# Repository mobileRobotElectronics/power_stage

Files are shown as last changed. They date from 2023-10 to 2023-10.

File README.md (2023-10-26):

# power-stage
Power stage designed for a mobile robot during a practical course at Karlsruhe Institute of Technology

This repository includes both the schematic and the PCD design of the power stage. Designed and edited using [KicCad7.0](https://www.kicad.org/).

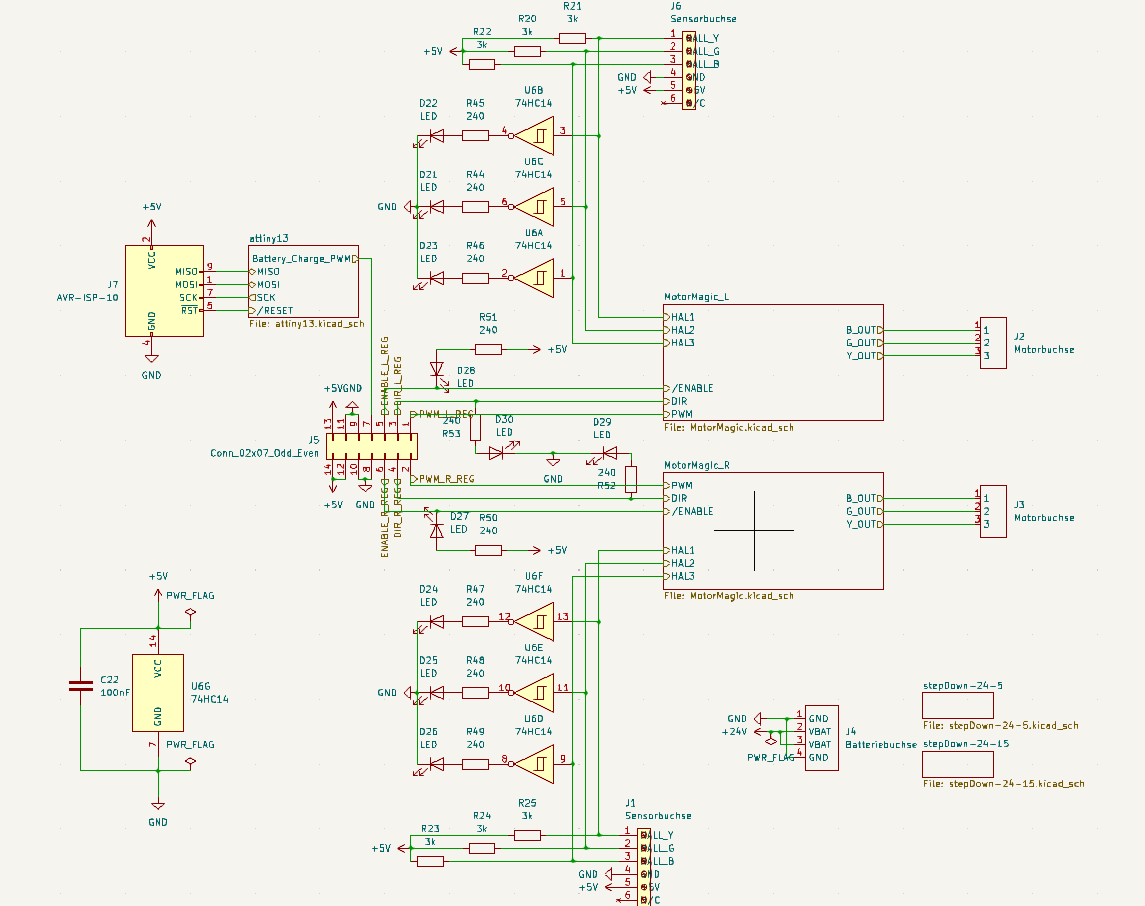
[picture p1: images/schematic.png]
schematic

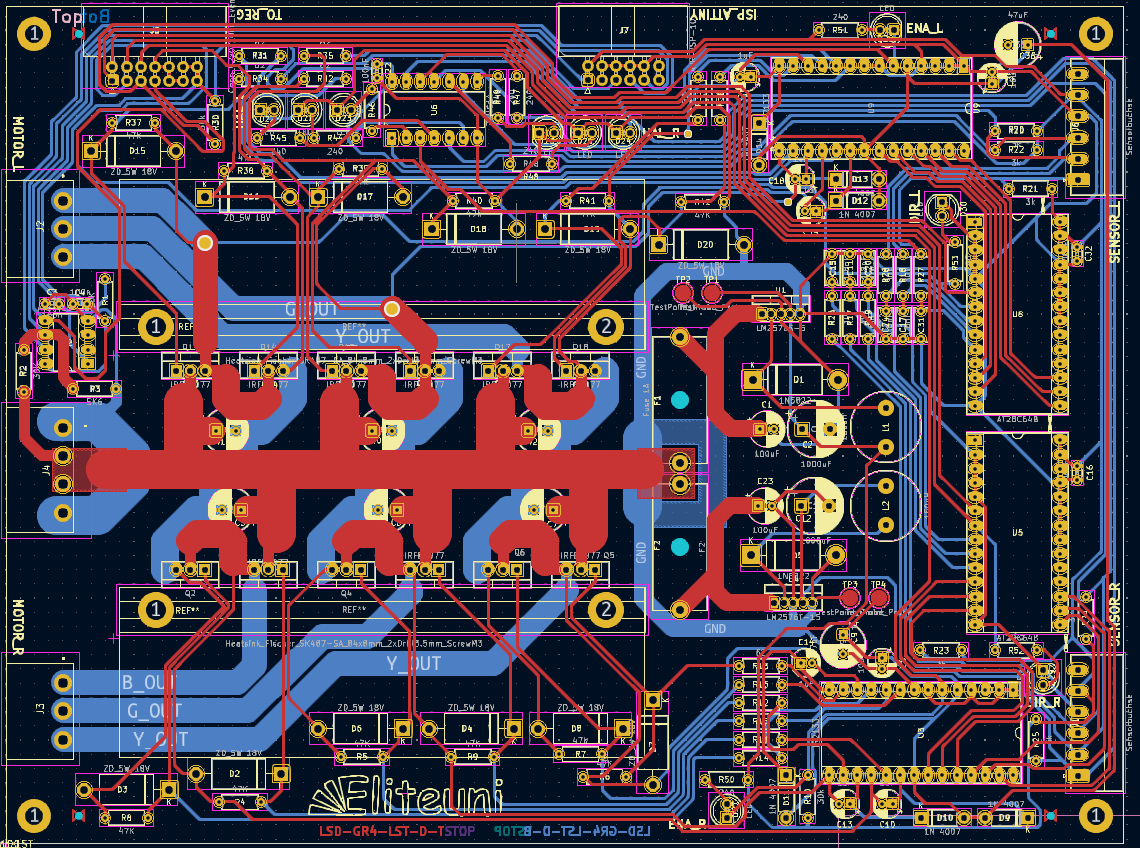
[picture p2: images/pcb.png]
pcd

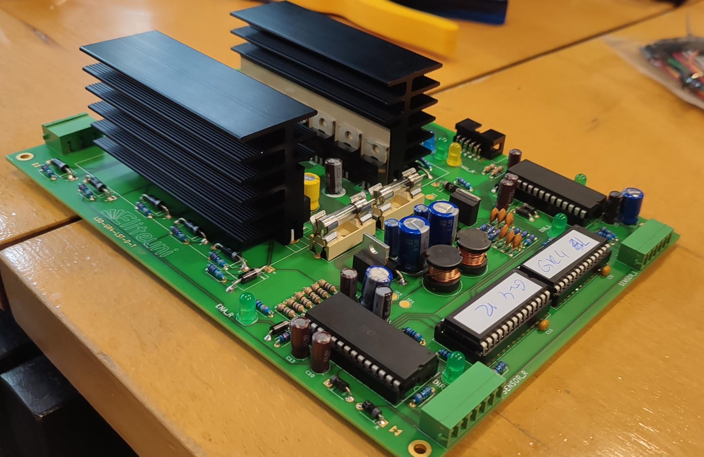
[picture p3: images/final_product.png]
final product


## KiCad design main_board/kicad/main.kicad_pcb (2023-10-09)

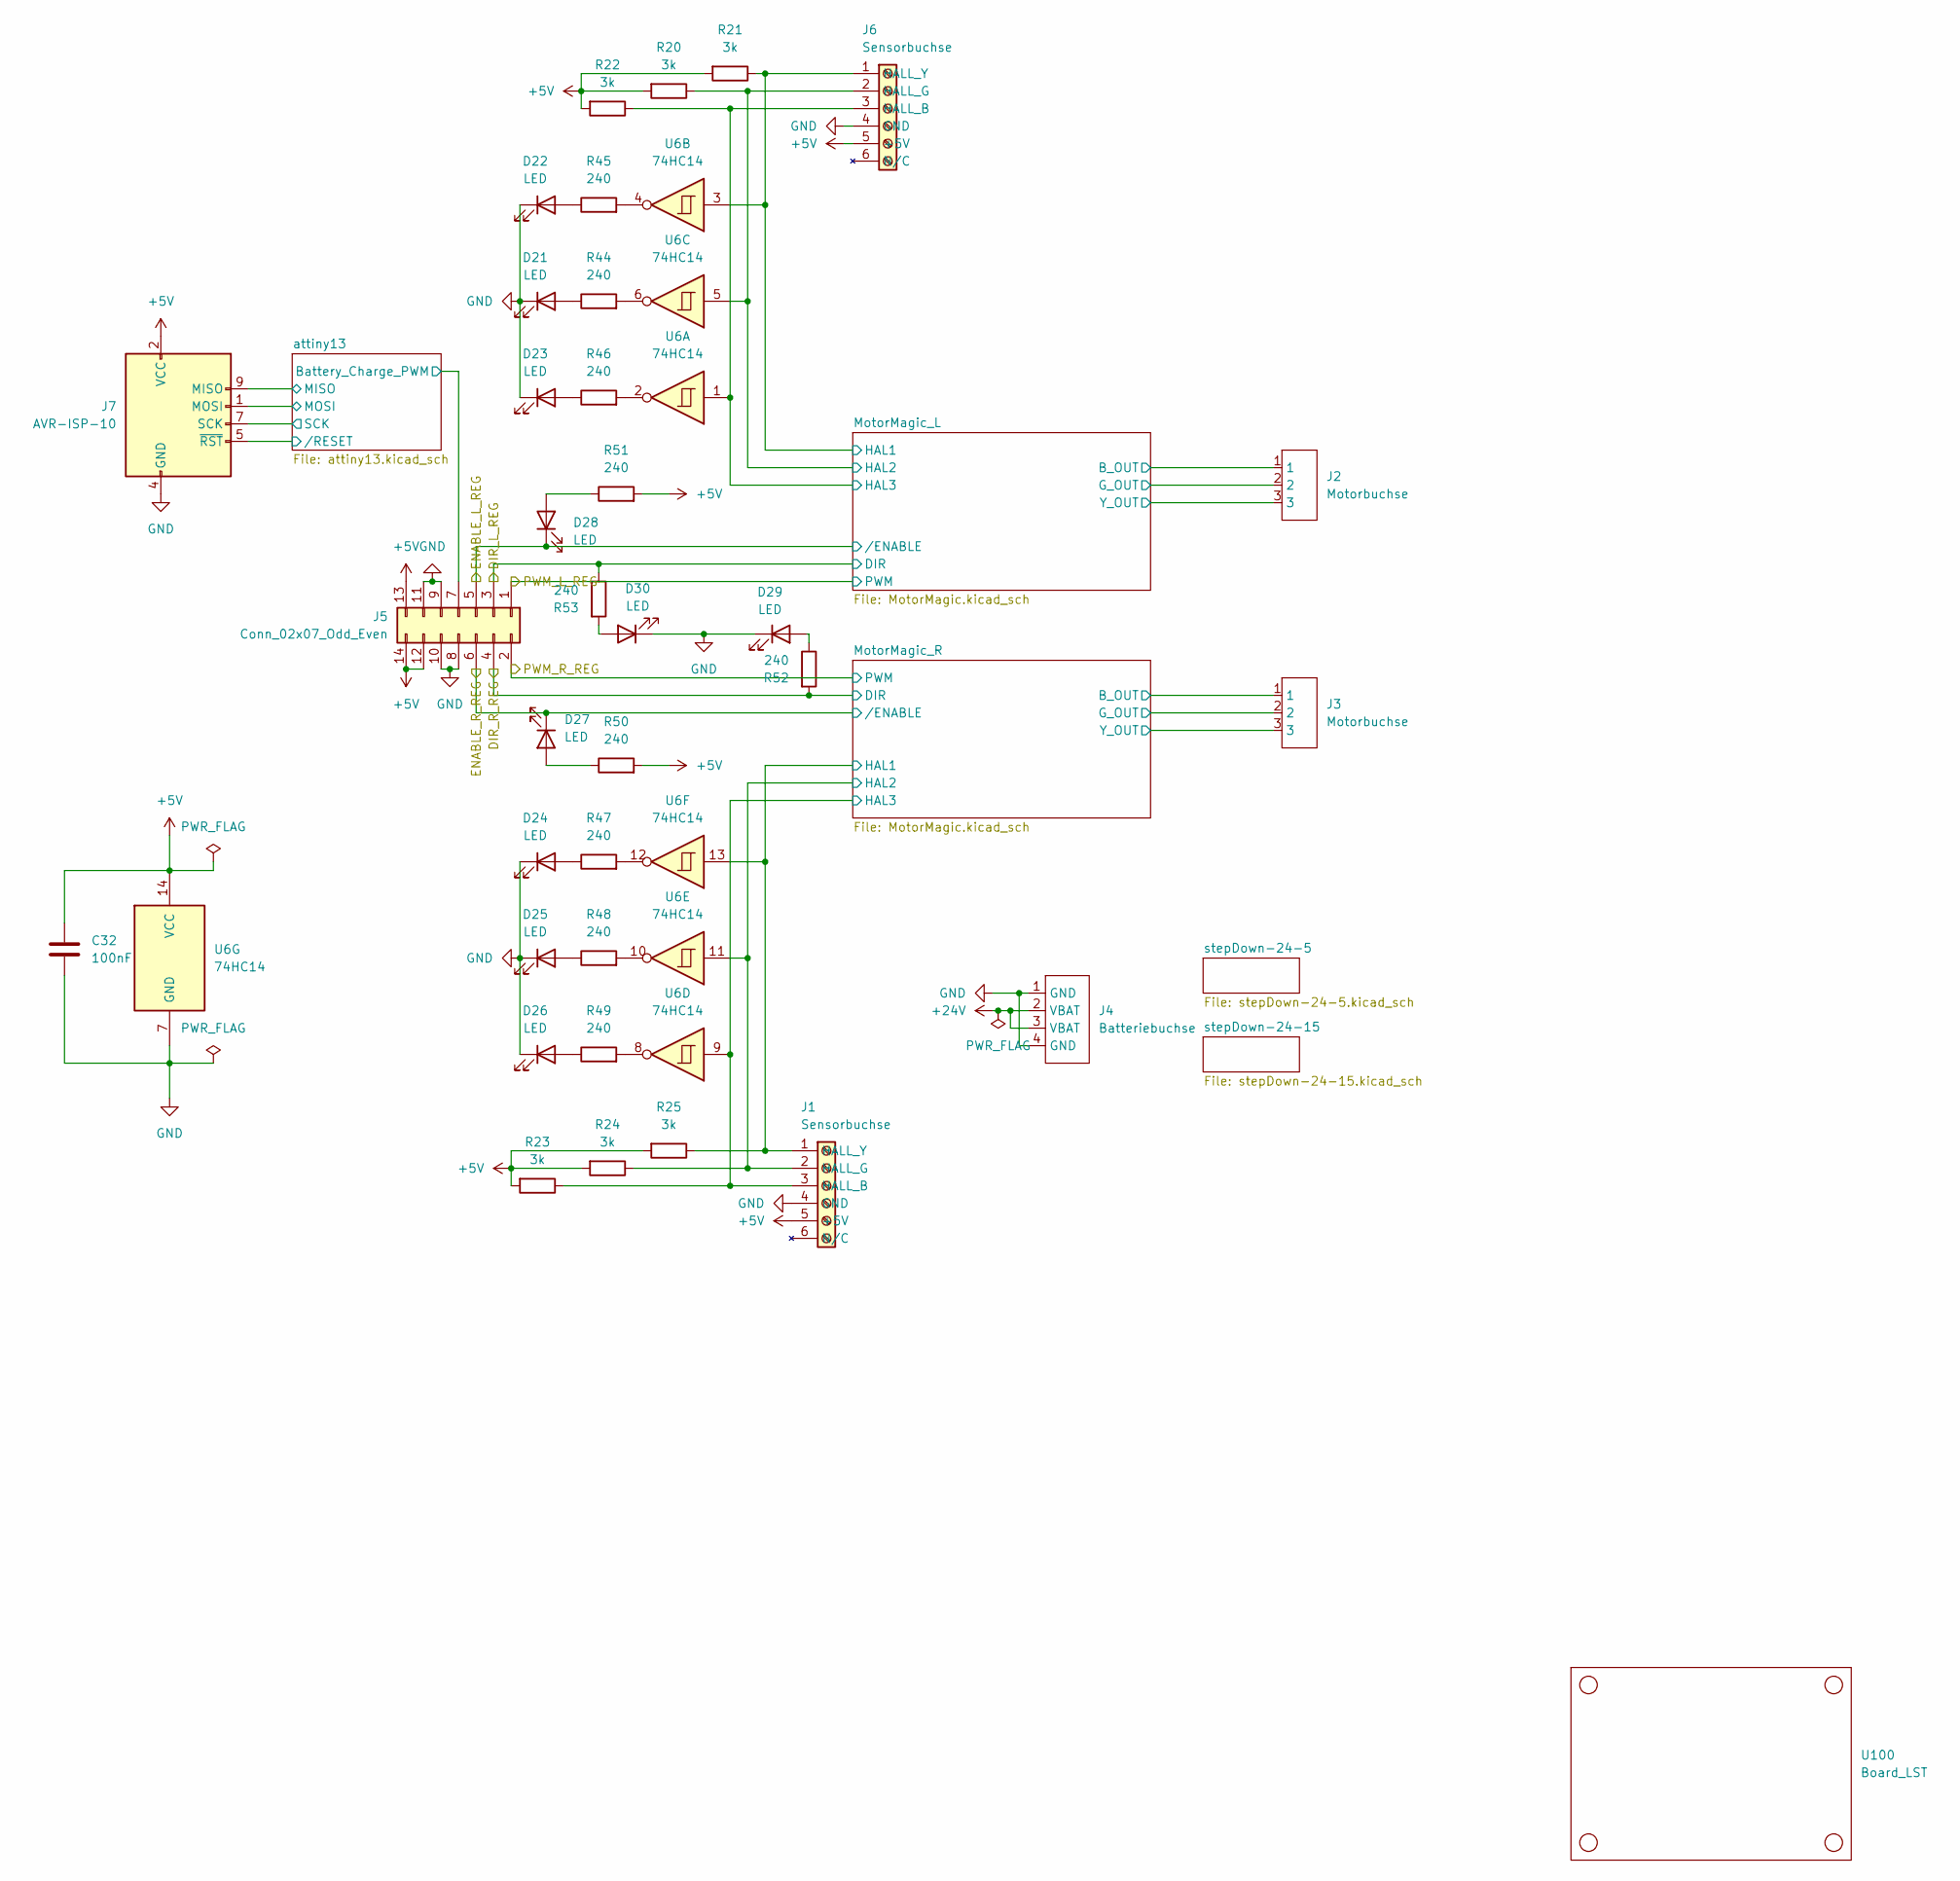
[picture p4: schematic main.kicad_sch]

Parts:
C32: 100nF; C_Disc_D3.0mm_W1.6mm_P2.50mm
D21, D22, D23, D24, D25, D26, D27, D28, D29, D30: LED; LED_D5.0mm
J1, J6: Sensorbuchse; PhoenixContact_MC_1,5_6-G-3.81_1x06_P3.81mm_Horizontal
J2, J3: Motorbuchse
J4: Batteriebuchse
J5: Conn_02x07_Odd_Even; IDC-Header_2x07_P2.54mm_Horizontal
J7: AVR-ISP-10; IDC-Header_2x06_P2.54mm_Horizontal
R20, R21, R22, R23, R24, R25: 3k; R_Axial_DIN0207_L6.3mm_D2.5mm_P7.62mm_Horizontal
R44, R45, R46, R47, R48, R49, R50, R51, R52, R53: 240; R_Axial_DIN0207_L6.3mm_D2.5mm_P7.62mm_Horizontal
U6: 74HC14; DIP-14_W10.16mm_LongPads
U100: Board_LST

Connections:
+24V: J4.2 (VBAT), J4.3 (VBAT); also elsewhere on the board
/DIR_L_REG: J5.3, R53.1; also elsewhere on the board
/DIR_R_REG: J5.4, R52.2; also elsewhere on the board
/ENABLE_L_REG: D28.1 (K), J5.5; also elsewhere on the board
/ENABLE_R_REG: D27.1 (K), J5.6; also elsewhere on the board
/MotorMagic_L/B_OUT: J2.1; also elsewhere on the board
/MotorMagic_L/G_OUT: J2.2; also elsewhere on the board
/MotorMagic_L/HAL1: J6.1 (HALL_Y), R21.1, U6.3; also elsewhere on the board
/MotorMagic_L/HAL2: J6.2 (HALL_G), R20.1, U6.5; also elsewhere on the board
/MotorMagic_L/HAL3: J6.3 (HALL_B), R22.1, U6.1; also elsewhere on the board
/MotorMagic_L/Y_OUT: J2.3; also elsewhere on the board
/MotorMagic_R/B_OUT: J3.1; also elsewhere on the board
/MotorMagic_R/G_OUT: J3.2; also elsewhere on the board
/MotorMagic_R/HAL1: J1.1 (HALL_Y), R25.1, U6.13; also elsewhere on the board
/MotorMagic_R/HAL2: J1.2 (HALL_G), R24.1, U6.11; also elsewhere on the board
/MotorMagic_R/HAL3: J1.3 (HALL_B), R23.1, U6.9; also elsewhere on the board
/MotorMagic_R/Y_OUT: J3.3; also elsewhere on the board
/PWM_L_REG: J5.1; also elsewhere on the board
/PWM_R_REG: J5.2; also elsewhere on the board
/attiny13/Battery_Charge_PWM: J5.7, J7.1 (MOSI); also elsewhere on the board
/attiny13/MISO: J7.9 (MISO); also elsewhere on the board
/attiny13/SCK: J7.7 (SCK); also elsewhere on the board
/attiny13//RESET: J7.5 (~RST); also elsewhere on the board
GND: C32.2, D21.1 (K), D22.1 (K), D23.1 (K), D24.1 (K), D25.1 (K), D26.1 (K), D29.1 (K), D30.1 (K), J1.4 (GND), J4.1 (GND), J4.4 (GND), J5.8, J5.9, J5.10, J5.11, J6.4 (GND), J7.4 (GND), J7.6 (GND), J7.8 (GND), J7.10 (GND), U6.7 (GND); also elsewhere on the board
unnamed: D21.2 (A), R44.1
unnamed: D22.2 (A), R45.1
unnamed: D23.2 (A), R46.1
unnamed: D24.2 (A), R47.1
unnamed: D25.2 (A), R48.1
unnamed: D26.2 (A), R49.1
unnamed: D27.2 (A), R50.1
unnamed: D28.2 (A), R51.1
unnamed: D29.2 (A), R52.1
unnamed: D30.2 (A), R53.2
unnamed: R44.2, U6.6
unnamed: R45.2, U6.4
unnamed: R46.2, U6.2
unnamed: R47.2, U6.12
unnamed: R48.2, U6.10
unnamed: R49.2, U6.8

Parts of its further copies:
C16, C22: 100nF; C_Disc_D3.0mm_W1.6mm_P2.50mm

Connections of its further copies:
GND: C16.2, C22.2; also elsewhere on the board

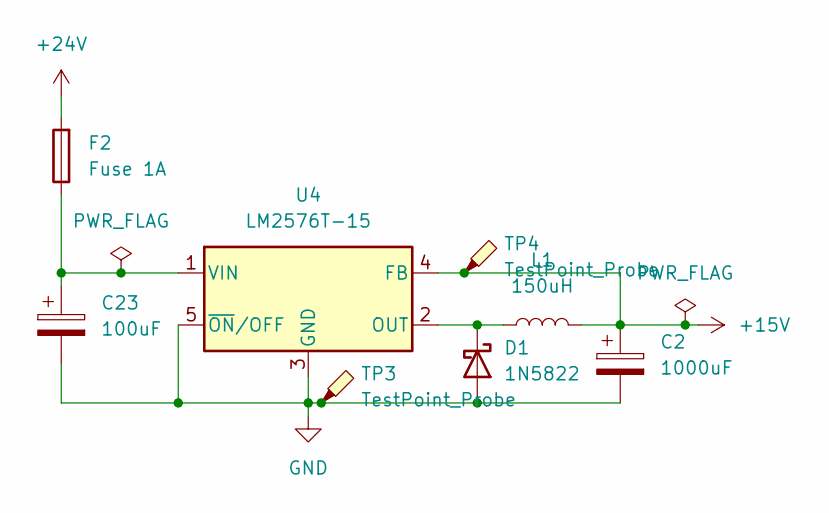
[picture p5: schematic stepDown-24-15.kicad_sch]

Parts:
C2: 1000uF; CP_Radial_D10.0mm_P5.00mm
C23: 100uF; CP_Radial_D6.3mm_P2.50mm
D1: 1N5822; D_DO-201AD_P15.24mm_Horizontal
F2: Fuse 1A; Fuseholder_Cylinder-5x20mm_Schurter_0031_8201_Horizontal_Op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
L1: 150uH; L_Radial_D12.5mm_P7.00mm_Fastron_09HCP
TP3, TP4: TestPoint_Probe; TestPoint_Pad_D3.0mm
U4: LM2576T-15; TO-220-5_Vertical

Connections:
+24V: F2.2; also elsewhere on the board
GND: C2.2, C23.2, D1.2 (A), TP3.1, U4.3 (GND), U4.5 (~ON/OFF); also elsewhere on the board

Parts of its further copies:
C12: 1000uF; CP_Radial_D10.0mm_P5.00mm
D5: 1N5822; D_DO-201AD_P15.24mm_Horizontal
L2: 150uH; L_Radial_D12.5mm_P7.00mm_Fastron_09HCP

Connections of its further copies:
GND: C12.2, D5.2 (A); also elsewhere on the board

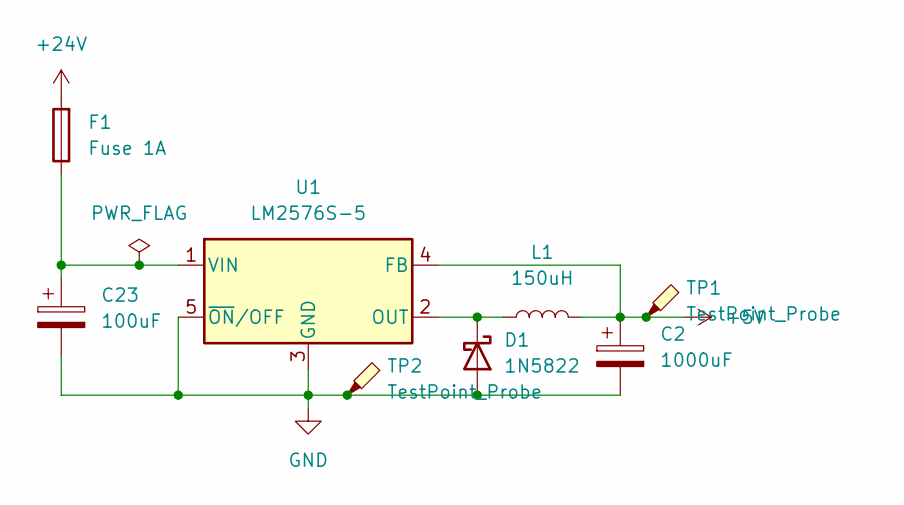
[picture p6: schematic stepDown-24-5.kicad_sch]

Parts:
C2: 1000uF; CP_Radial_D10.0mm_P5.00mm
C23: 100uF; CP_Radial_D6.3mm_P2.50mm
D1: 1N5822; D_DO-201AD_P15.24mm_Horizontal
F1: Fuse 1A; Fuseholder_Cylinder-5x20mm_Schurter_0031_8201_Horizontal_Op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
L1: 150uH; L_Radial_D12.5mm_P7.00mm_Fastron_09HCP
TP1, TP2: TestPoint_Probe; TestPoint_Pad_D3.0mm
U1: LM2576S-5; TO-220-5_Vertical

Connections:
+24V: F1.2; also elsewhere on the board
GND: C2.2, C23.2, D1.2 (A), TP2.1, U1.3 (GND), U1.5 (~ON/OFF); also elsewhere on the board

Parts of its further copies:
C1: 100uF; CP_Radial_D6.3mm_P2.50mm

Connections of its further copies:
GND: C1.2; also elsewhere on the board

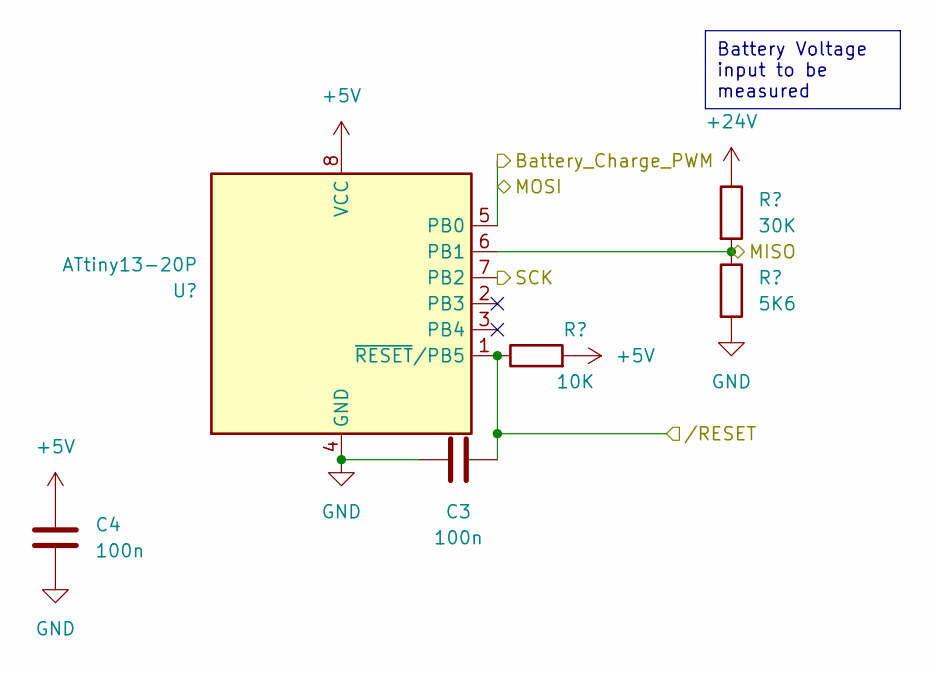
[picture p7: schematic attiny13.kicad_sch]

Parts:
C3, C4: 100n; C_Disc_D3.0mm_W1.6mm_P2.50mm
R1: 10K; R_Axial_DIN0207_L6.3mm_D2.5mm_P7.62mm_Horizontal
R2: 30K; R_Axial_DIN0207_L6.3mm_D2.5mm_P7.62mm_Horizontal
R3: 5K6; R_Axial_DIN0207_L6.3mm_D2.5mm_P7.62mm_Horizontal
U2: ATtiny13-20P; DIP-8_W7.62mm_LongPads

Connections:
+24V: R2.1; also elsewhere on the board
/attiny13/Battery_Charge_PWM: U2.5 (PB0); also elsewhere on the board
/attiny13/MISO: R2.2, R3.1, U2.6 (PB1); also elsewhere on the board
/attiny13/SCK: U2.7 (PB2); also elsewhere on the board
/attiny13//RESET: C3.2, R1.1, U2.1 (~RESET/PB5); also elsewhere on the board
GND: C3.1, C4.2, R3.2, U2.4 (GND); also elsewhere on the board

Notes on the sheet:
Battery Voltage input to be measured

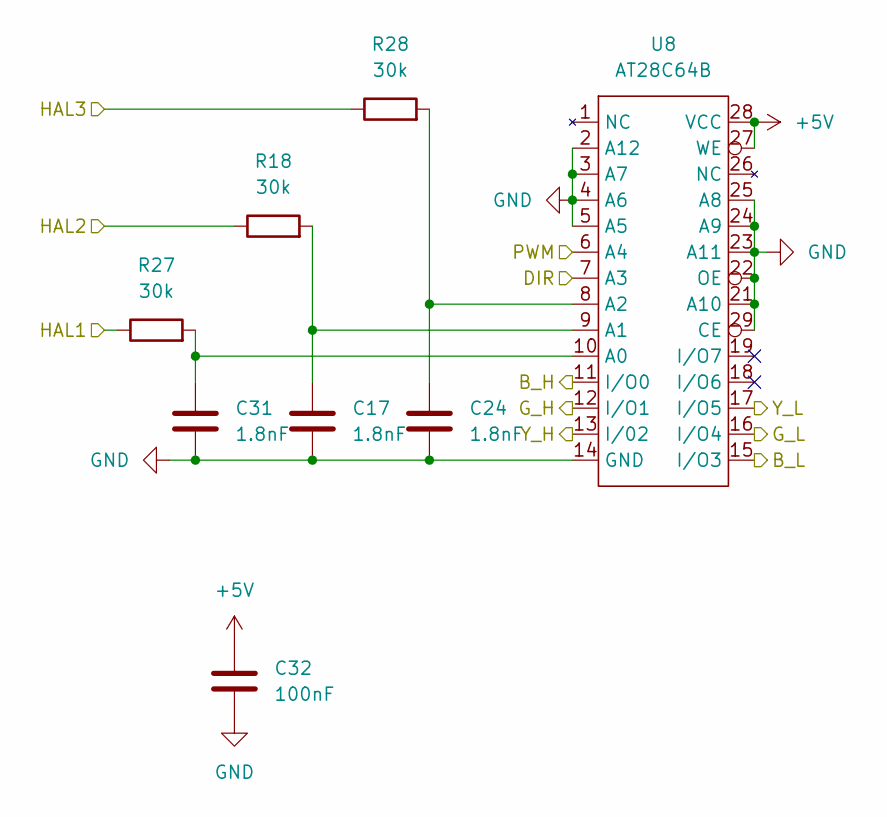
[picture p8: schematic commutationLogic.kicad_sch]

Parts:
C17, C24, C31: 1.8nF; C_Disc_D6.0mm_W2.5mm_P5.00mm
C32: 100nF; C_Disc_D3.0mm_W1.6mm_P2.50mm
R18, R27, R28: 30k; R_Axial_DIN0207_L6.3mm_D2.5mm_P7.62mm_Horizontal
U8: AT28C64B; DIP-28_W15.24mm_Socket_LongPads

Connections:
/DIR_L_REG: U8.7 (A3); also elsewhere on the board
/MotorMagic_L/HAL1: R27.1; also elsewhere on the board
/MotorMagic_L/HAL2: R18.1; also elsewhere on the board
/MotorMagic_L/HAL3: R28.1; also elsewhere on the board
/MotorMagic_L/bridgeDriver2/B_H_IN: U8.11 (I/O0); also elsewhere on the board
/MotorMagic_L/bridgeDriver2/B_L_IN: U8.15 (I/O3); also elsewhere on the board
/MotorMagic_L/bridgeDriver2/G_H_IN: U8.12 (I/O1); also elsewhere on the board
/MotorMagic_L/bridgeDriver2/G_L_IN: U8.16 (I/O4); also elsewhere on the board
/MotorMagic_L/bridgeDriver2/Y_H_IN: U8.13 (I/02); also elsewhere on the board
/MotorMagic_L/bridgeDriver2/Y_L_IN: U8.17 (I/O5); also elsewhere on the board
/PWM_L_REG: U8.6 (A4); also elsewhere on the board
GND: C17.2, C24.2, C31.2, C32.2, U8.2 (A12), U8.3 (A7), U8.4 (A6), U8.5 (A5), U8.14 (GND), U8.21 (A10), U8.22 (OE), U8.23 (A11), U8.24 (A9), U8.25 (A8), U8.29 (CE); also elsewhere on the board
unnamed: C31.1, R27.2, U8.10 (A0)
unnamed: C17.1, R18.2, U8.9 (A1)
unnamed: C24.1, R28.2, U8.8 (A2)

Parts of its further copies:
C11, C15, C20: 1.8nF; C_Disc_D6.0mm_W2.5mm_P5.00mm
C16: 100nF; C_Disc_D3.0mm_W1.6mm_P2.50mm
R17, R19, R26: 30k; R_Axial_DIN0207_L6.3mm_D2.5mm_P7.62mm_Horizontal
U5: AT28C64B; DIP-28_W15.24mm_Socket_LongPads

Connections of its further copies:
/DIR_R_REG: U5.7 (A3); also elsewhere on the board
/MotorMagic_R/HAL1: R26.1; also elsewhere on the board
/MotorMagic_R/HAL2: R17.1; also elsewhere on the board
/MotorMagic_R/HAL3: R19.1; also elsewhere on the board
/MotorMagic_R/bridgeDriver2/B_H_IN: U5.11 (I/O0); also elsewhere on the board
/MotorMagic_R/bridgeDriver2/B_L_IN: U5.15 (I/O3); also elsewhere on the board
/MotorMagic_R/bridgeDriver2/G_H_IN: U5.12 (I/O1); also elsewhere on the board
/MotorMagic_R/bridgeDriver2/G_L_IN: U5.16 (I/O4); also elsewhere on the board
/MotorMagic_R/bridgeDriver2/Y_H_IN: U5.13 (I/02); also elsewhere on the board
/MotorMagic_R/bridgeDriver2/Y_L_IN: U5.17 (I/O5); also elsewhere on the board
/PWM_R_REG: U5.6 (A4); also elsewhere on the board
GND: C11.2, C15.2, C16.2, C20.2, U5.2 (A12), U5.3 (A7), U5.4 (A6), U5.5 (A5), U5.14 (GND), U5.21 (A10), U5.22 (OE), U5.23 (A11), U5.24 (A9), U5.25 (A8); also elsewhere on the board
unnamed: C15.1, R26.2, U5.10 (A0)
unnamed: C11.1, R17.2, U5.9 (A1)
unnamed: C20.1, R19.2, U5.8 (A2)

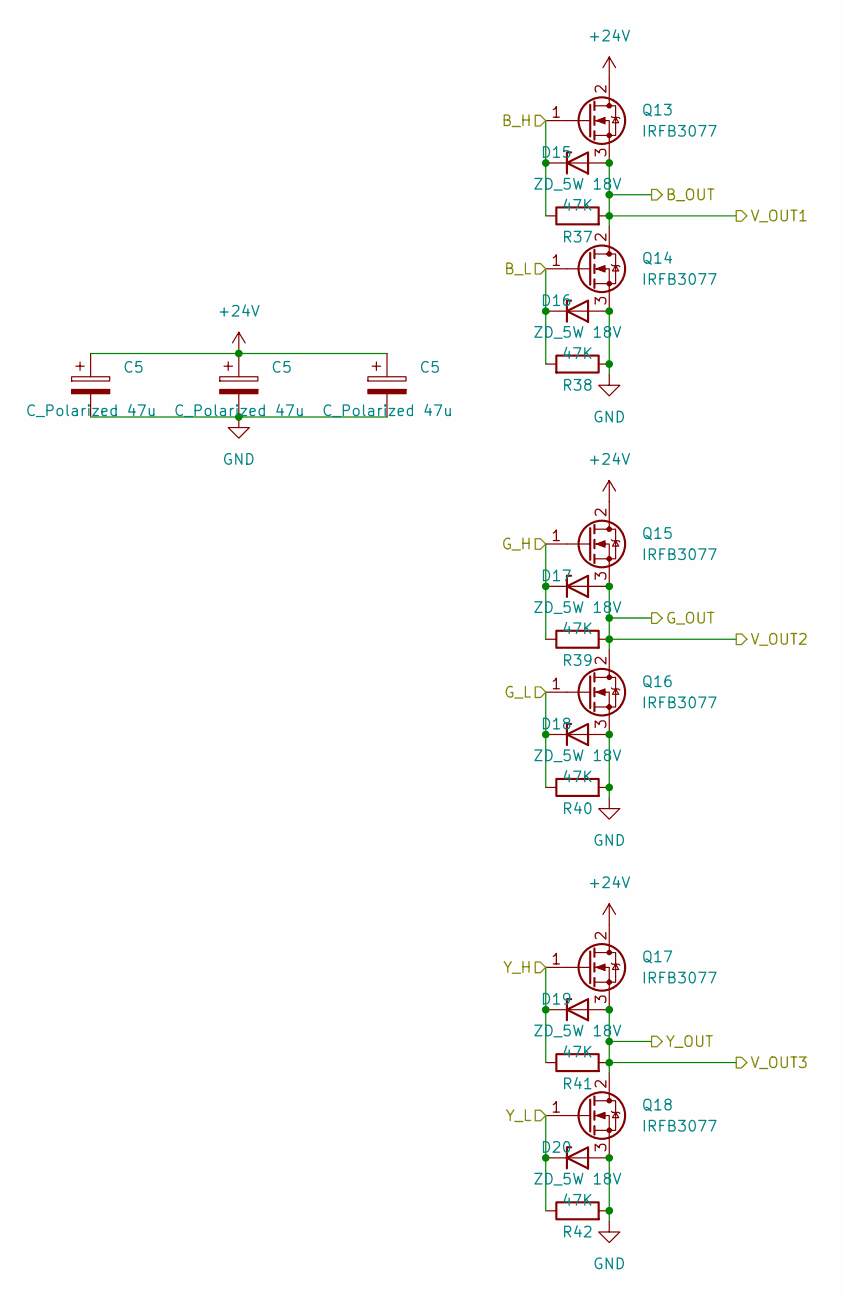
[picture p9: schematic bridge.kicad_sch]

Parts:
C5: C_Polarized 47u; CP_Radial_D8.0mm_P3.50mm
D15, D16, D17, D18, D19, D20: ZD_5W 18V; D_DO-201_P15.24mm_Horizontal
Q13, Q14, Q15, Q16, Q17, Q18: IRFB3077; TO-220-3_Vertical
R37, R38, R39, R40, R41, R42: 47K; R_Axial_DIN0207_L6.3mm_D2.5mm_P7.62mm_Horizontal

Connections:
+24V: C5.1, Q13.2 (D), Q15.2 (D), Q17.2 (D); also elsewhere on the board
/MotorMagic_L/B_OUT: D15.2 (A), Q13.3 (S), Q14.2 (D), R37.2; also elsewhere on the board
/MotorMagic_L/G_OUT: D17.2 (A), Q15.3 (S), Q16.2 (D), R39.2; also elsewhere on the board
/MotorMagic_L/Y_OUT: D19.2 (A), Q17.3 (S), Q18.2 (D), R41.2; also elsewhere on the board
/MotorMagic_L/bridge2/B_H: D15.1 (K), Q13.1 (G), R37.1; also elsewhere on the board
/MotorMagic_L/bridge2/B_L: D16.1 (K), Q14.1 (G), R38.2; also elsewhere on the board
/MotorMagic_L/bridge2/G_H: D17.1 (K), Q15.1 (G), R39.1; also elsewhere on the board
/MotorMagic_L/bridge2/G_L: D18.1 (K), Q16.1 (G), R40.1; also elsewhere on the board
/MotorMagic_L/bridge2/Y_H: D19.1 (K), Q17.1 (G), R41.1; also elsewhere on the board
/MotorMagic_L/bridge2/Y_L: D20.1 (K), Q18.1 (G), R42.1; also elsewhere on the board
GND: C5.2, D16.2 (A), D18.2 (A), D20.2 (A), Q14.3 (S), Q16.3 (S), Q18.3 (S), R38.1, R40.2, R42.2; also elsewhere on the board

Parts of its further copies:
C6, C7, C40, C41, C42: C_Polarized 47u; CP_Radial_D8.0mm_P3.50mm
D2, D3, D4, D6, D7, D8: ZD_5W 18V; D_DO-201_P15.24mm_Horizontal
Q1, Q2, Q3, Q4, Q5, Q6: IRFB3077; TO-220-3_Vertical
R4, R5, R6, R7, R8, R9: 47K; R_Axial_DIN0207_L6.3mm_D2.5mm_P7.62mm_Horizontal

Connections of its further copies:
+24V: C6.1, C7.1, C40.1, C41.1, C42.1, Q1.2 (D), Q3.2 (D), Q5.2 (D); also elsewhere on the board
/MotorMagic_R/B_OUT: D2.2 (A), Q1.3 (S), Q2.2 (D), R4.2; also elsewhere on the board
/MotorMagic_R/G_OUT: D4.2 (A), Q3.3 (S), Q4.2 (D), R9.2; also elsewhere on the board
/MotorMagic_R/Y_OUT: D7.2 (A), Q5.3 (S), Q6.2 (D), R6.2; also elsewhere on the board
/MotorMagic_R/bridge2/B_H: D2.1 (K), Q1.1 (G), R4.1; also elsewhere on the board
/MotorMagic_R/bridge2/B_L: D3.1 (K), Q2.1 (G), R8.2; also elsewhere on the board
/MotorMagic_R/bridge2/G_H: D4.1 (K), Q3.1 (G), R9.1; also elsewhere on the board
/MotorMagic_R/bridge2/G_L: D6.1 (K), Q4.1 (G), R5.1; also elsewhere on the board
/MotorMagic_R/bridge2/Y_H: D7.1 (K), Q5.1 (G), R6.1; also elsewhere on the board
/MotorMagic_R/bridge2/Y_L: D8.1 (K), Q6.1 (G), R7.1; also elsewhere on the board
GND: C6.2, C7.2, C40.2, C41.2, C42.2, D3.2 (A), D6.2 (A), D8.2 (A), Q2.3 (S), Q4.3 (S), Q6.3 (S), R5.2, R7.2, R8.1; also elsewhere on the board

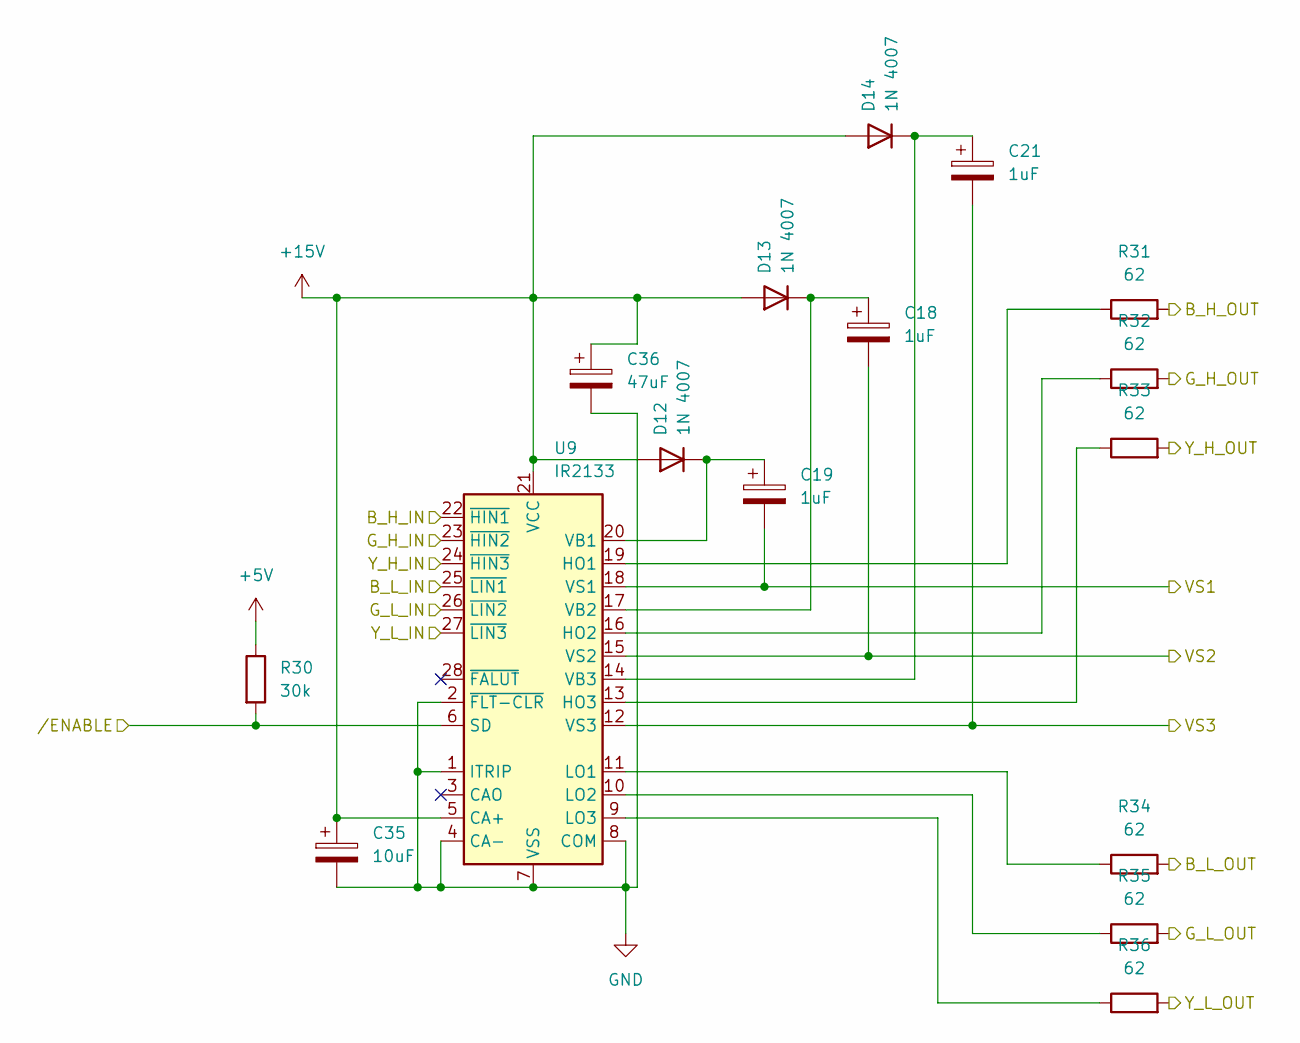
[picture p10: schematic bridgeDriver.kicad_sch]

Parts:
C18, C19, C21: 1uF; CP_Radial_D5.0mm_P2.00mm
C35: 10uF; CP_Radial_D5.0mm_P2.00mm
C36: 47uF; CP_Radial_D8.0mm_P3.50mm
D12, D13, D14: 1N 4007; D_DO-41_SOD81_P7.62mm_Horizontal
R30: 30k; R_Axial_DIN0207_L6.3mm_D2.5mm_P7.62mm_Horizontal
R31, R32, R33, R34, R35, R36: 62; R_Axial_DIN0207_L6.3mm_D2.5mm_P7.62mm_Horizontal
U9: IR2133; DIP-28_W15.24mm_Socket_LongPads

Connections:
/ENABLE_L_REG: R30.2, U9.6 (SD); also elsewhere on the board
/MotorMagic_L/B_OUT: C19.2, U9.18 (VS1); also elsewhere on the board
/MotorMagic_L/G_OUT: C18.2, U9.15 (VS2); also elsewhere on the board
/MotorMagic_L/Y_OUT: C21.2, U9.12 (VS3); also elsewhere on the board
/MotorMagic_L/bridge2/B_H: R31.2; also elsewhere on the board
/MotorMagic_L/bridge2/B_L: R34.2; also elsewhere on the board
/MotorMagic_L/bridge2/G_H: R32.2; also elsewhere on the board
/MotorMagic_L/bridge2/G_L: R35.2; also elsewhere on the board
/MotorMagic_L/bridge2/Y_H: R33.2; also elsewhere on the board
/MotorMagic_L/bridge2/Y_L: R36.2; also elsewhere on the board
/MotorMagic_L/bridgeDriver2/B_H_IN: U9.22 (~HIN1); also elsewhere on the board
/MotorMagic_L/bridgeDriver2/B_L_IN: U9.25 (~LIN1); also elsewhere on the board
/MotorMagic_L/bridgeDriver2/G_H_IN: U9.23 (~HIN2); also elsewhere on the board
/MotorMagic_L/bridgeDriver2/G_L_IN: U9.26 (~LIN2); also elsewhere on the board
/MotorMagic_L/bridgeDriver2/Y_H_IN: U9.24 (~HIN3); also elsewhere on the board
/MotorMagic_L/bridgeDriver2/Y_L_IN: U9.27 (~LIN3); also elsewhere on the board
GND: C35.2, C36.2, U9.1 (ITRIP), U9.2 (~FLT-CLR), U9.4 (CA-), U9.7 (VSS), U9.8 (COM); also elsewhere on the board
unnamed: C19.1, D12.1 (K), U9.20 (VB1)
unnamed: C18.1, D13.1 (K), U9.17 (VB2)
unnamed: C21.1, D14.1 (K), U9.14 (VB3)
unnamed: R31.1, U9.19 (HO1)
unnamed: R32.1, U9.16 (HO2)
unnamed: R33.1, U9.13 (HO3)
unnamed: R34.1, U9.11 (LO1)
unnamed: R35.1, U9.10 (LO2)
unnamed: R36.1, U9.9 (LO3)

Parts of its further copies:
C8: 10uF; CP_Radial_D5.0mm_P2.00mm
C9: 47uF; CP_Radial_D8.0mm_P3.50mm
C10, C13, C14: 1uF; CP_Radial_D5.0mm_P2.00mm
D9, D10, D11: 1N 4007; D_DO-41_SOD81_P7.62mm_Horizontal
R10: 30k; R_Axial_DIN0207_L6.3mm_D2.5mm_P7.62mm_Horizontal
R11, R12, R13, R14, R15, R16: 62; R_Axial_DIN0207_L6.3mm_D2.5mm_P7.62mm_Horizontal
U3: IR2133; DIP-28_W15.24mm_Socket_LongPads

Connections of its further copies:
/ENABLE_R_REG: R10.2, U3.6 (SD); also elsewhere on the board
/MotorMagic_R/B_OUT: C10.2, U3.18 (VS1); also elsewhere on the board
/MotorMagic_R/G_OUT: C13.2, U3.15 (VS2); also elsewhere on the board
/MotorMagic_R/Y_OUT: C14.2, U3.12 (VS3); also elsewhere on the board
/MotorMagic_R/bridge2/B_H: R11.2; also elsewhere on the board
/MotorMagic_R/bridge2/B_L: R14.2; also elsewhere on the board
/MotorMagic_R/bridge2/G_H: R12.2; also elsewhere on the board
/MotorMagic_R/bridge2/G_L: R15.2; also elsewhere on the board
/MotorMagic_R/bridge2/Y_H: R13.2; also elsewhere on the board
/MotorMagic_R/bridge2/Y_L: R16.2; also elsewhere on the board
/MotorMagic_R/bridgeDriver2/B_H_IN: U3.22 (~HIN1); also elsewhere on the board
/MotorMagic_R/bridgeDriver2/B_L_IN: U3.25 (~LIN1); also elsewhere on the board
/MotorMagic_R/bridgeDriver2/G_H_IN: U3.23 (~HIN2); also elsewhere on the board
/MotorMagic_R/bridgeDriver2/G_L_IN: U3.26 (~LIN2); also elsewhere on the board
/MotorMagic_R/bridgeDriver2/Y_H_IN: U3.24 (~HIN3); also elsewhere on the board
/MotorMagic_R/bridgeDriver2/Y_L_IN: U3.27 (~LIN3); also elsewhere on the board
GND: C8.2, C9.2, U3.1 (ITRIP), U3.2 (~FLT-CLR), U3.4 (CA-), U3.7 (VSS), U3.8 (COM); also elsewhere on the board
unnamed: C10.1, D9.1 (K), U3.20 (VB1)
unnamed: C13.1, D10.1 (K), U3.17 (VB2)
unnamed: C14.1, D11.1 (K), U3.14 (VB3)
unnamed: R11.1, U3.19 (HO1)
unnamed: R12.1, U3.16 (HO2)
unnamed: R13.1, U3.13 (HO3)
unnamed: R14.1, U3.11 (LO1)
unnamed: R15.1, U3.10 (LO2)
unnamed: R16.1, U3.9 (LO3)

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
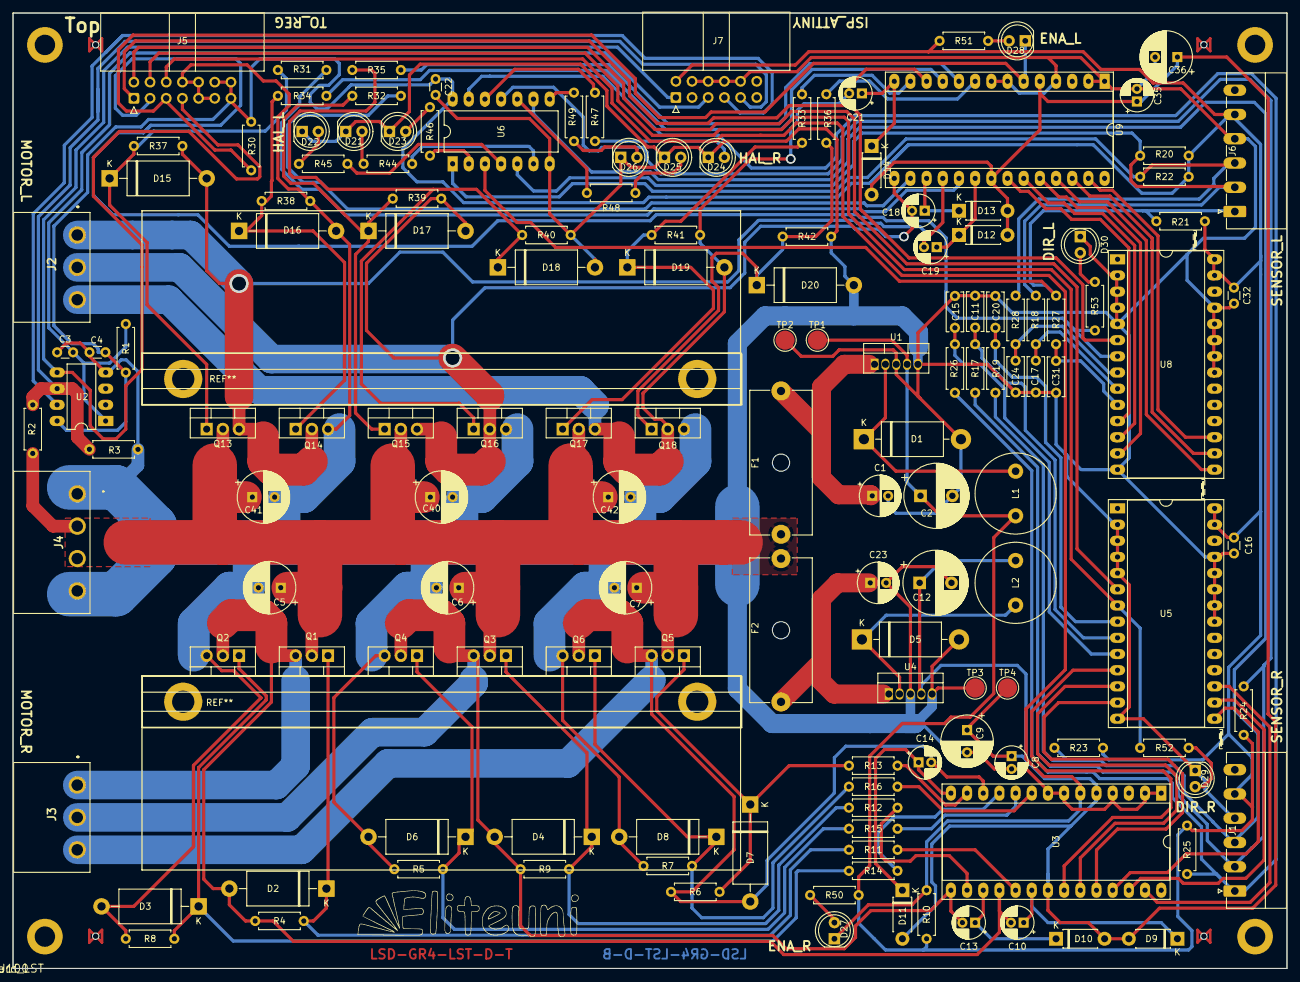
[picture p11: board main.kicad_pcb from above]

Board: 2 copper layers, 200.0 x 150.0 mm, 148 parts (0 on the bottom side), 94 nets.

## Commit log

2023-10-02 started work on main board
    [main.kicad_pcb, main.kicad_sch]
2023-10-02 started bridge design
    [attiny13.kicad_sch, bridge.kicad_sch, main.kicad_sch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]
2023-10-02 changes to bridge design
    [bridge.kicad_sch, main.kicad_sch]
2023-10-04 added bridge driver stub
    [bridgeDriver.kicad_sch, main.kicad_sch]
2023-10-04 bridge driver almost done
    [bridgeDriver.kicad_sch]
2023-10-04 added hierarchy for 15v stepdown
    [attiny13.kicad_sch, main.kicad_sch, stepDown-24-15.kicad_sch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]
2023-10-04 implemented 15v stepdown
    [bridge.kicad_sch, main.kicad_sch, stepDown-24-15.kicad_sch]
2023-10-04 added communication logic
    [bridgeDriver.kicad_sch, commutationLogic.kicad_sch, main.kicad_sch]
2023-10-04 added cancel diodes and pullup to bridge
    [bridge.kicad_sch]
2023-10-04 added isp interface to attiny
    [attiny13.kicad_sch, bridge.kicad_sch]
2023-10-04 revamped root and bridge
    [bridge.kicad_sch, bridgeDriver.kicad_sch, commutationLogic.kicad_sch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]
2023-10-04 added ISP socket for attiny
    [bridge.kicad_sch, bridgeDriver.kicad_sch, commutationLogic.kicad_sch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]
2023-10-04 added pull up resistor values
    [bridgeDriver.kicad_sch, commutationLogic.kicad_sch, main.kicad_sch]
2023-10-04 fixed pull up resistor values
    [bridgeDriver.kicad_sch, commutationLogic.kicad_sch, main.kicad_sch]
2023-10-04 added funny fun file
    [bridgeDriver.kicad_sch, untitled.kicad_sch]
2023-10-04 added component values
    [attiny13.kicad_sch]
2023-10-04 added bridge driver values
    [bridgeDriver.kicad_sch]
2023-10-04 added component values to bridge
    [bridge.kicad_sch]
2023-10-04 added eeprom values
    [bridgeDriver.kicad_sch, commutationLogic.kicad_sch]
2023-10-04 added first capacitor value for stepdown
    [stepDown-24-15.kicad_sch, stepDown-24-5.kicad_sch]
2023-10-05 renamed motor magic file
    [MotorMagic.kicad_sch, bridge.kicad_sch, bridgeDriver.kicad_sch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]
2023-10-05 added LEDS and fuses
    [bridge.kicad_sch, bridgeDriver.kicad_sch, commutationLogic.kicad_sch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]
2023-10-05 resolved ERC
    [MotorMagic.kicad_sch, bridge.kicad_sch, bridgeDriver.kicad_sch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]
2023-10-05 added probe point
    [stepDown-24-15.kicad_sch, stepDown-24-5.kicad_sch]
2023-10-05 updated to post review state
    [MotorMagic.kicad_sch, attiny13.kicad_sch, bridge.kicad_sch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]
2023-10-05 corrected issues detected in review
    [MotorMagic.kicad_sch, attiny13.kicad_sch, bridge.kicad_sch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]
2023-10-06 added footprints
    [attiny13.kicad_sch, bridge.kicad_sch, bridgeDriver.kicad_sch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]
2023-10-06 implemented bridge and first bridge driver as well as both step converters on the pcd layout
    [bridge.kicad_sch, main.kicad_pcb, main.kicad_sch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]
2023-10-07 rerouted some lines, also added attiny
    [main.kicad_pcb]
2023-10-07 rerouted some lines
    [main.kicad_pcb]
2023-10-07 rerouted lines
    [main.kicad_pcb]
2023-10-07 installed REG connector
    [main.kicad_pcb]
2023-10-07 rerouted more lines, also implemented HAL LEDS
    [main.kicad_pcb, main.kicad_sch]
2023-10-07 added text markers
    [main.kicad_pcb]
2023-10-08 moved logic sockets
    [main.kicad_pcb]
2023-10-09 more optimization
    [main.kicad_pcb]
2023-10-09 solved DRC
    [main.kicad_pcb]
2023-10-09 finalized board
    [main.kicad_pcb]
